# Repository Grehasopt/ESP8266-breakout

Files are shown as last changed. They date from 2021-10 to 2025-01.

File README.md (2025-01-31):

# ESP8266-breakout
A breadboard friendly ESP12E/F breakout with all I/O pins available, flash/reset buttons onboard, and pins ready to use with FTDI module

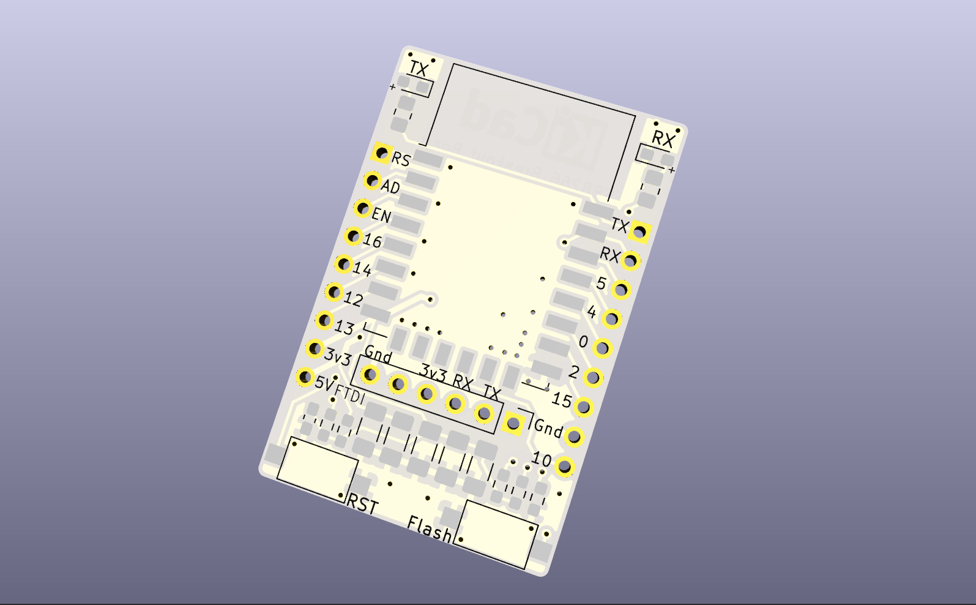
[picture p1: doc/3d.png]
3d view


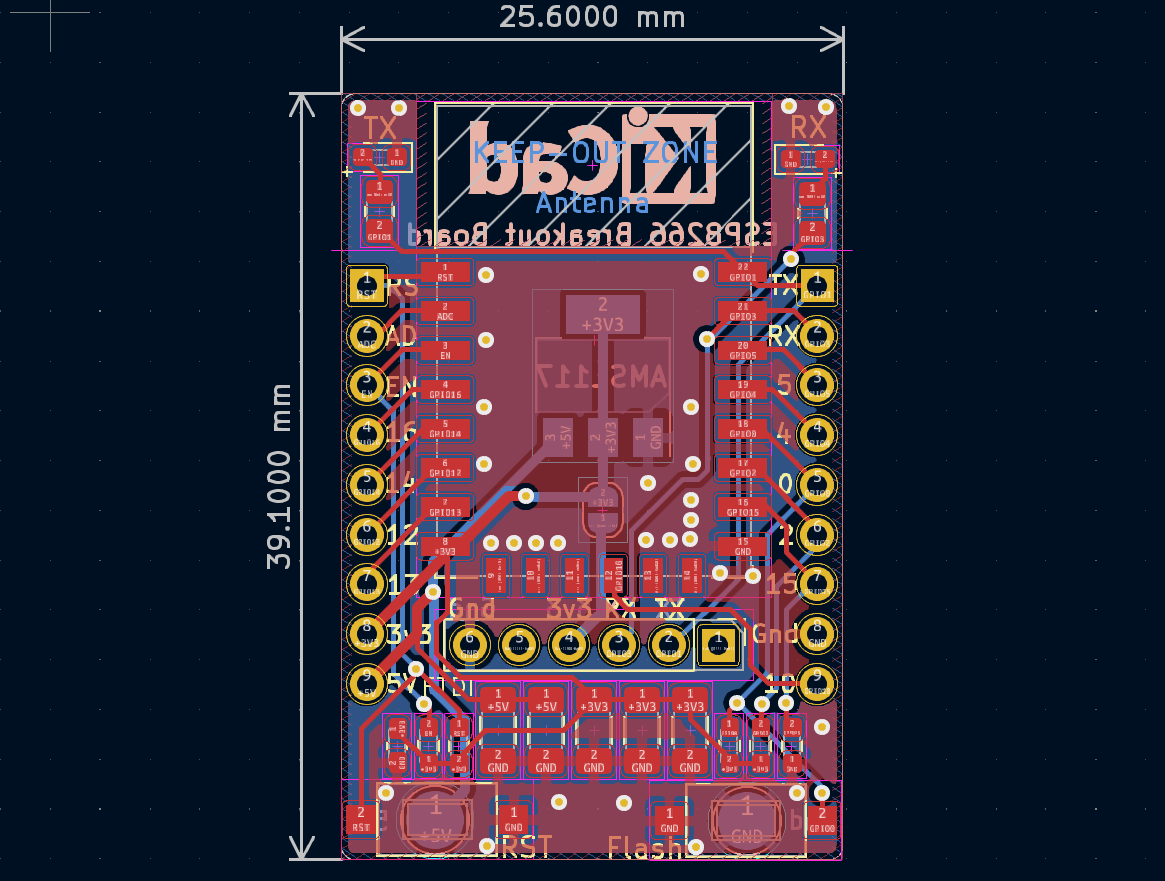
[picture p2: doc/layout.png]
layout


## License
This project is licensed under the CERN-OHL-S-2.0 (applies from the very first commit on Mar 7, 2021) with the added condition that it may not be used for commercial purposes without prior permission from the license holder.

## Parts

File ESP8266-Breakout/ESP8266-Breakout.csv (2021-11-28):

Comment | Designator | Footprint | LCSC
100nF | C102,C103 | Capacitor_SMD:C_1206_3216Metric_Pad1.33x1.80mm_HandSolder | C24497
10uF | C101,C104 | Capacitor_SMD:C_1206_3216Metric_Pad1.33x1.80mm_HandSolder | C13585
0.1uF | C501 | Capacitor_SMD:C_0603_1608Metric_Pad1.08x0.95mm_HandSolder | C14663
47uF | C502 | Capacitor_SMD:C_1206_3216Metric_Pad1.33x1.80mm_HandSolder | C96123
TX | D501 | LED_SMD:LED_0603_1608Metric_Pad1.05x0.95mm_HandSolder | C72041
RX | D502 | LED_SMD:LED_0603_1608Metric_Pad1.05x0.95mm_HandSolder | C72041
Conn_01x09_Female | J101,J102 | Custom:PinHeader_1x09_P2.54mm_Vertical_without_silkscrean
FTDI | J501 | Connector_PinHeader_2.54mm:PinHeader_1x06_P2.54mm_Vertical
Power | JP501 | Jumper:SolderJumper-2_P1.3mm_Bridged_RoundedPad1.0x1.5mm
10K | R501,R502,R503,R505,R506 | Resistor_SMD:R_0603_1608Metric_Pad0.98x0.95mm_HandSolder | C25804
15 | R504,R507 | Resistor_SMD:R_0805_2012Metric_Pad1.20x1.40mm_HandSolder | C17480
Flash | SW501 | Button_Switch_SMD:SW_SPST_CK_RS282G05A3 | C398053
RST | SW502 | Button_Switch_SMD:SW_SPST_CK_RS282G05A3 | C398053
TestPoint | TP101,TP102 | TestPoint:TestPoint_Pad_D3.0mm
AMS1117-3.3 | U101 | Package_TO_SOT_SMD:SOT-223-3_TabPin2

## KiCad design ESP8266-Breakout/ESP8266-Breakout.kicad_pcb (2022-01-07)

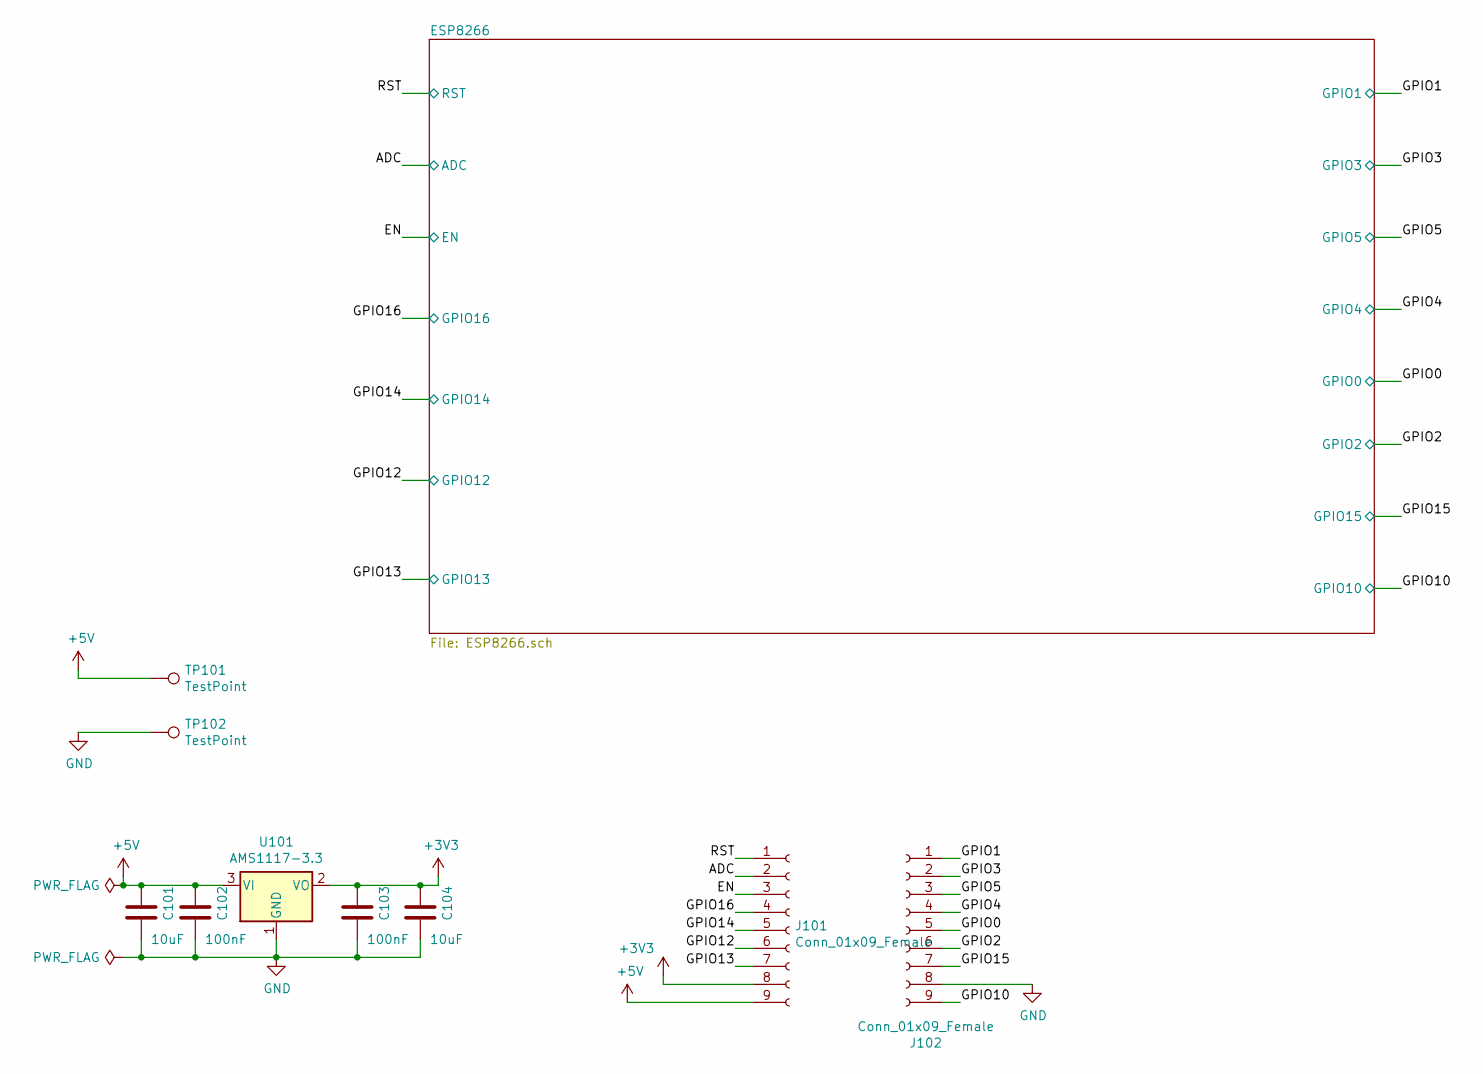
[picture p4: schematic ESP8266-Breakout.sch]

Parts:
C101, C104: 10uF; C_1206_3216Metric_Pad1.33x1.80mm_HandSolder; LCSC C13585
C102, C103: 100nF; C_1206_3216Metric_Pad1.33x1.80mm_HandSolder; LCSC C24497
J101, J102: Conn_01x09_Female; PinHeader_1x09_P2.54mm_Vertical_without_silkscrean
TP101, TP102: TestPoint; TestPoint_Pad_D3.0mm
U101: AMS1117-3.3; SOT-223-3_TabPin2

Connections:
+3V3: C103.1, C104.1, J101.8, U101.2 (VO); also elsewhere on the board
+5V: C101.1, C102.1, J101.9, TP101.1, U101.3 (VI)
/ADC: J101.2; also elsewhere on the board
/EN: J101.3; also elsewhere on the board
/GPIO0: J102.5; also elsewhere on the board
/GPIO1: J102.1; also elsewhere on the board
/GPIO2: J102.6; also elsewhere on the board
/GPIO3: J102.2; also elsewhere on the board
/GPIO4: J102.4; also elsewhere on the board
/GPIO5: J102.3; also elsewhere on the board
/GPIO10: J102.9; also elsewhere on the board
/GPIO12: J101.6; also elsewhere on the board
/GPIO13: J101.7; also elsewhere on the board
/GPIO14: J101.5; also elsewhere on the board
/GPIO15: J102.7; also elsewhere on the board
/GPIO16: J101.4; also elsewhere on the board
/RST: J101.1; also elsewhere on the board
GND: C101.2, C102.2, C103.2, C104.2, J102.8, TP102.1, U101.1 (GND); also elsewhere on the board

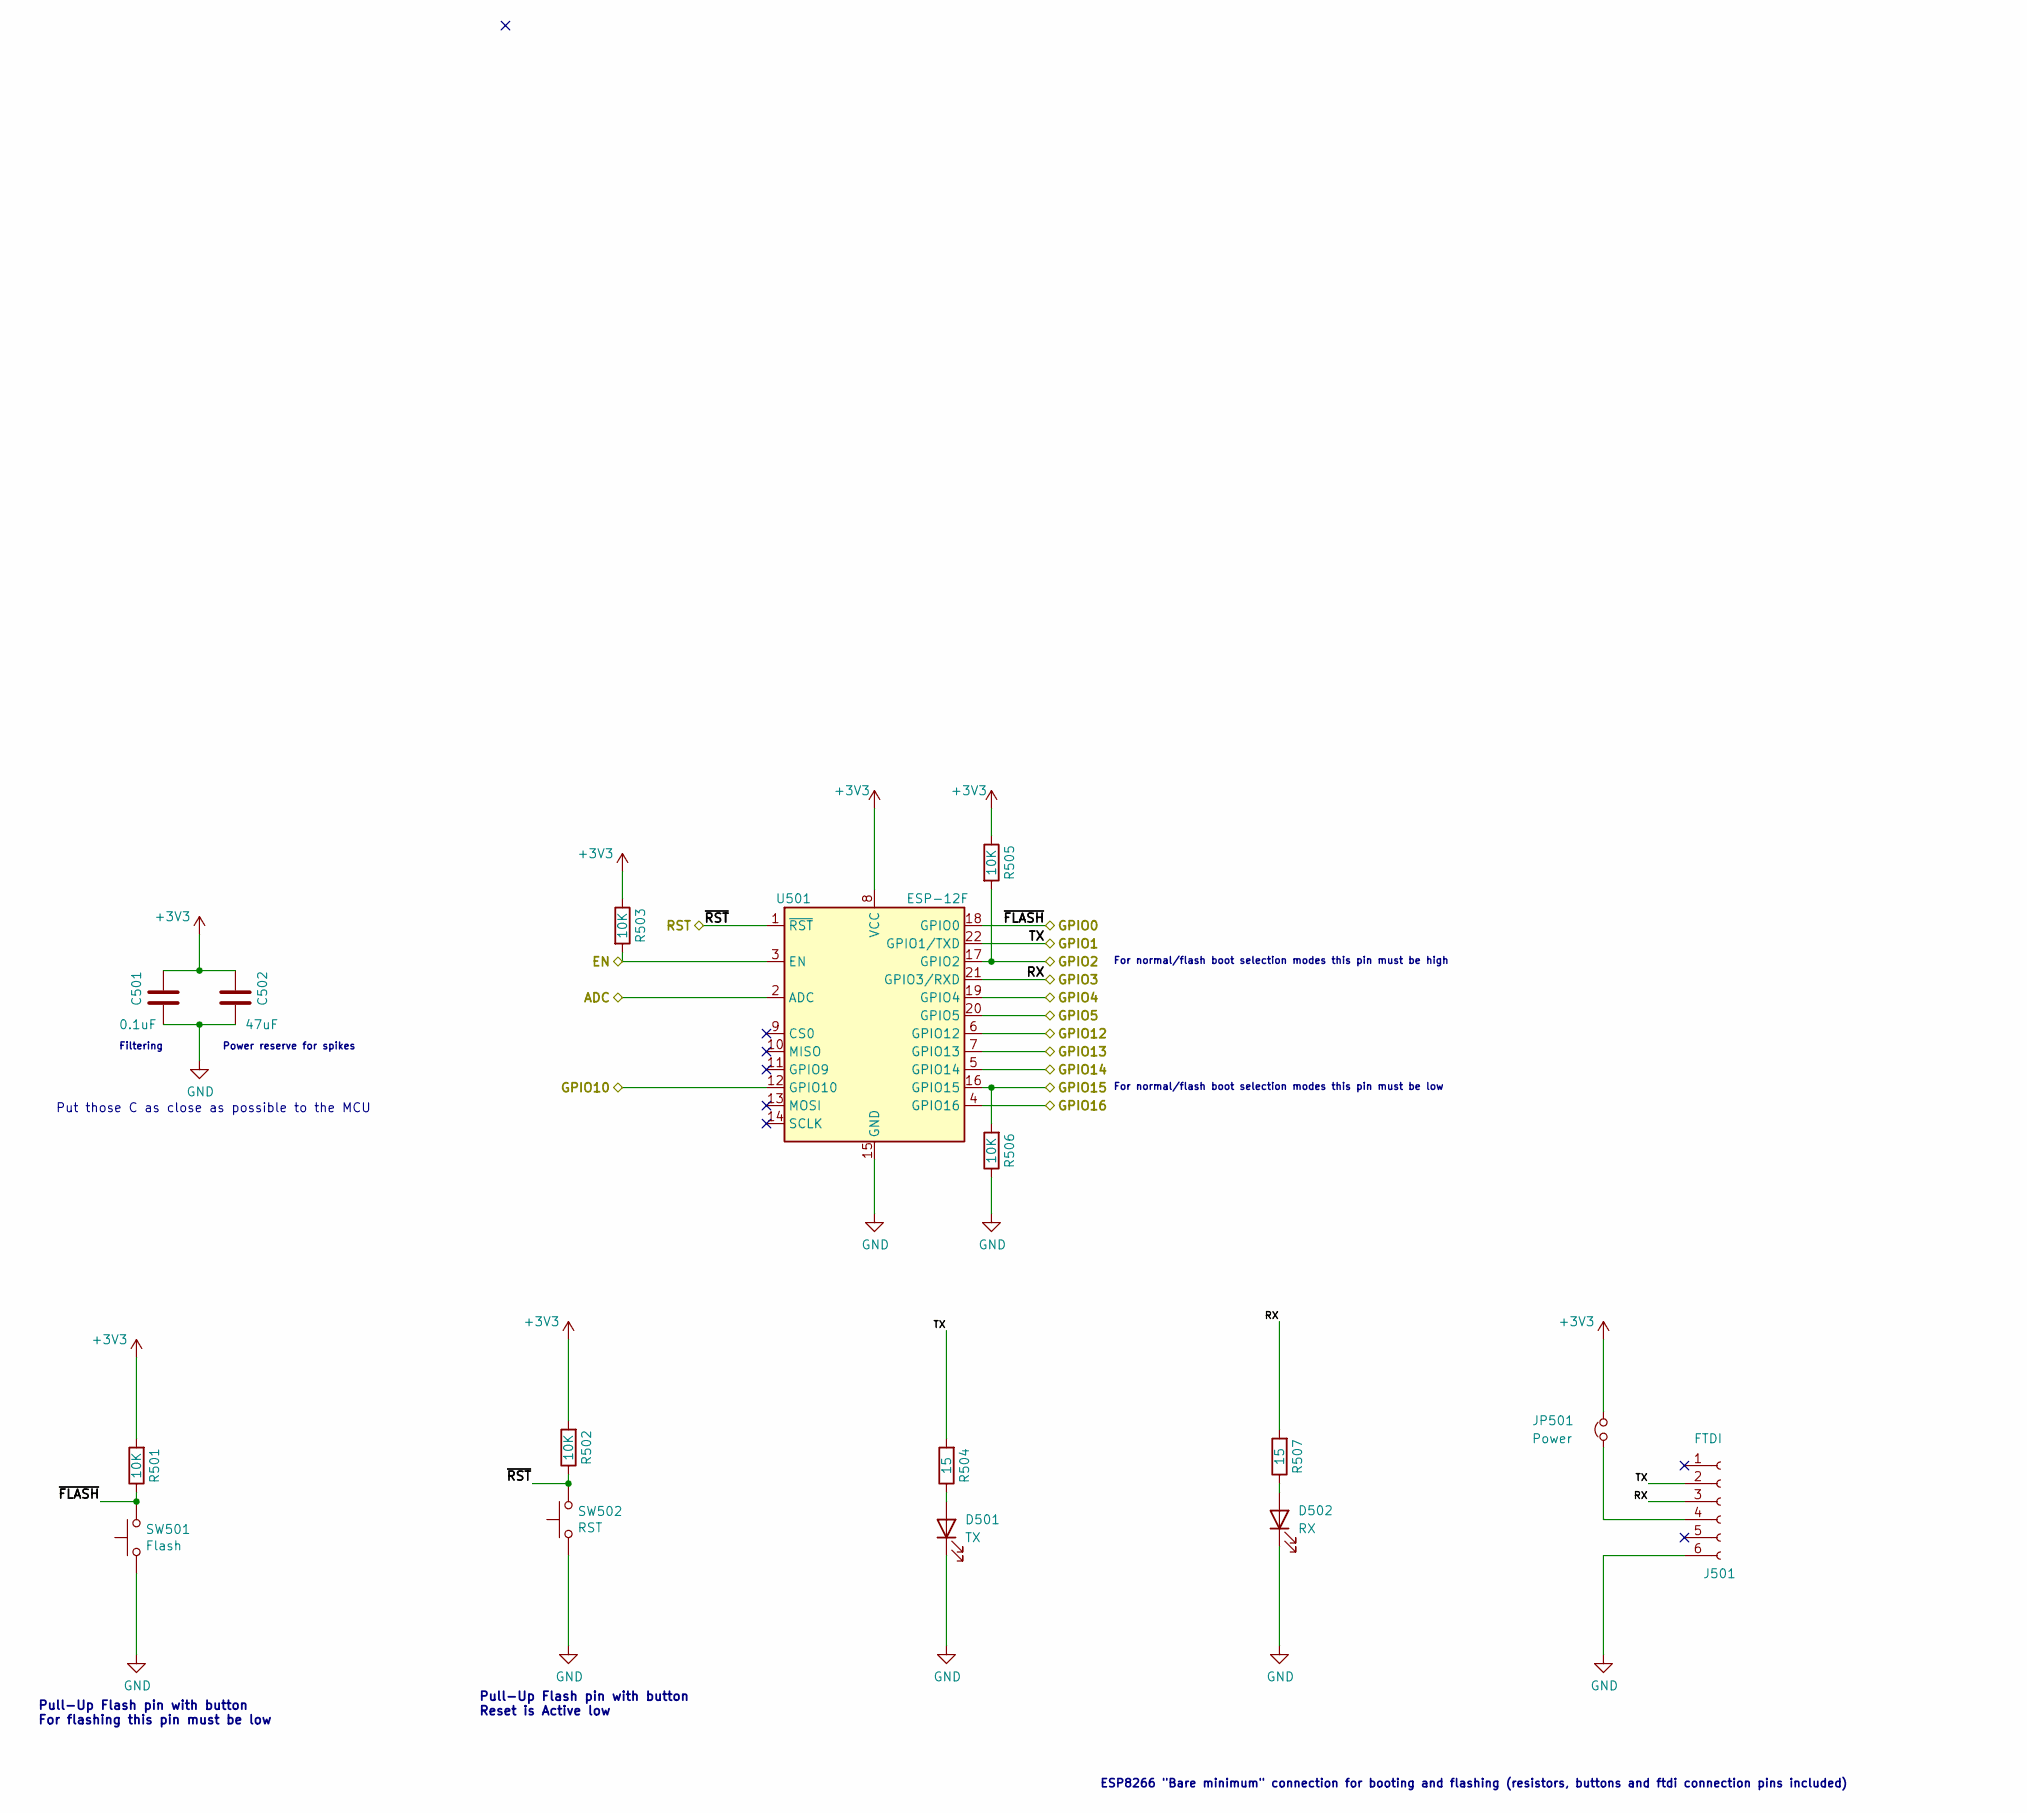
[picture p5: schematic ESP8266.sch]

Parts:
C501: 0.1uF; C_0603_1608Metric_Pad1.08x0.95mm_HandSolder; LCSC C14663
C502: 47uF; C_1206_3216Metric_Pad1.33x1.80mm_HandSolder; LCSC C96123
D501: TX; LED_0603_1608Metric_Pad1.05x0.95mm_HandSolder; LCSC C72041
D502: RX; LED_0603_1608Metric_Pad1.05x0.95mm_HandSolder; LCSC C72041
J501: FTDI; PinHeader_1x06_P2.54mm_Vertical
JP501: Power; SolderJumper-2_P1.3mm_Bridged_RoundedPad1.0x1.5mm
R501, R502, R503, R505, R506: 10K; R_0603_1608Metric_Pad0.98x0.95mm_HandSolder; LCSC C25804
R504, R507: 15; R_0805_2012Metric_Pad1.20x1.40mm_HandSolder; LCSC C17480
SW501: Flash; SW_SPST_CK_RS282G05A3; LCSC C398053
SW502: RST; SW_SPST_CK_RS282G05A3; LCSC C398053
U501: ESP-12F; ESP-12E; LCSC C82891

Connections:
+3V3: C501.1, C502.1, JP501.2, R501.2, R502.2, R503.1, R505.1, U501.8 (VCC); also elsewhere on the board
/ADC: U501.2 (ADC); also elsewhere on the board
/EN: R503.2, U501.3 (EN); also elsewhere on the board
/GPIO0: R501.1, SW501.2, U501.18 (GPIO0); also elsewhere on the board
/GPIO1: J501.2, R504.2, U501.22 (GPIO1/TXD); also elsewhere on the board
/GPIO2: R505.2, U501.17 (GPIO2); also elsewhere on the board
/GPIO3: J501.3, R507.2, U501.21 (GPIO3/RXD); also elsewhere on the board
/GPIO4: U501.19 (GPIO4); also elsewhere on the board
/GPIO5: U501.20 (GPIO5); also elsewhere on the board
/GPIO10: U501.12 (GPIO10); also elsewhere on the board
/GPIO12: U501.6 (GPIO12); also elsewhere on the board
/GPIO13: U501.7 (GPIO13); also elsewhere on the board
/GPIO14: U501.5 (GPIO14); also elsewhere on the board
/GPIO15: R506.2, U501.16 (GPIO15); also elsewhere on the board
/GPIO16: U501.4 (GPIO16); also elsewhere on the board
/RST: R502.1, SW502.2, U501.1 (~RST); also elsewhere on the board
GND: C501.2, C502.2, D501.1 (K), D502.1 (K), J501.6, R506.1, SW501.1, SW502.1, U501.15 (GND); also elsewhere on the board
unnamed: D501.2 (A), R504.1
unnamed: D502.2 (A), R507.1
unnamed: J501.4, JP501.1

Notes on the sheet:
ESP8266 "Bare minimum" connection for booting and flashing (resistors, buttons and ftdi connection pins included)
For normal/flash boot selection modes this pin must be high
For normal/flash boot selection modes this pin must be low
Pull-Up Flash pin with button Reset is Active low
Filtering
Power reserve for spikes
Pull-Up Flash pin with button For flashing this pin must be low
Put those C as close as possible to the MCU

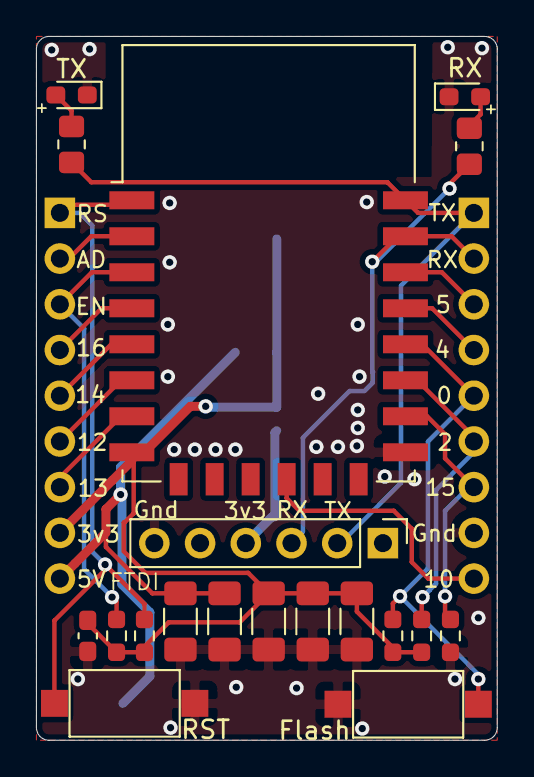
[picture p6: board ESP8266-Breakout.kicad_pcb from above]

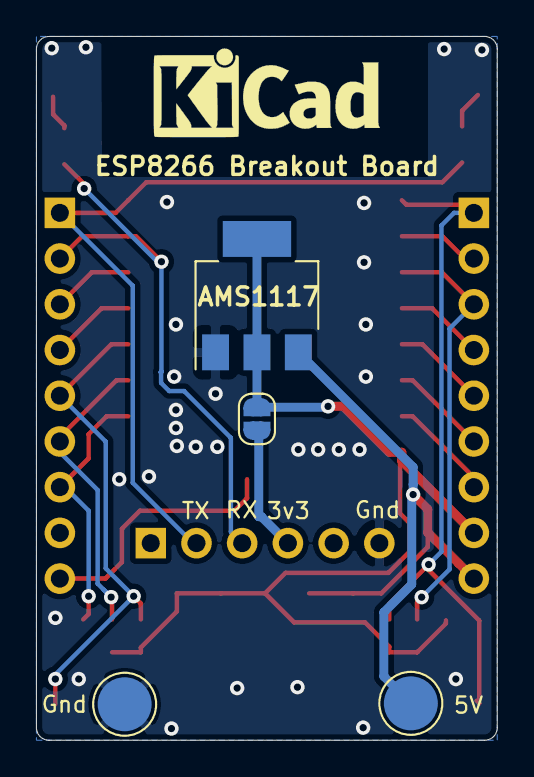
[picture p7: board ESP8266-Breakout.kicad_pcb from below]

Board: 2 copper layers, 25.6 x 39.1 mm, 25 parts (4 on the bottom side), 21 nets.

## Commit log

2021-07-18 Init - problem with scematic (empty)
    [ESP8266-Breakout.kicad_pcb, ESP8266-Breakout.sch]
2021-10-11 New version completed, shematic + pcb wired
    [ESP8266-Breakout.kicad_pcb, ESP8266.sch]
2021-11-28 Single and panel board views added
    [ESP8266-Breakout-B_Cu.gbr, ESP8266-Breakout-B_Mask.gbr, ESP8266-Breakout-B_Paste.gbr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]
2022-01-07 Release 2
    [ESP8266-Breakout-panel-B_Cu.gbr, ESP8266-Breakout-panel-B_Mask.gbr, ESP8266-Breakout-panel-B_Paste.gbr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]
